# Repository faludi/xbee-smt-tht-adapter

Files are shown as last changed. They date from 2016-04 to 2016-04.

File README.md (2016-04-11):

# xbee-smt-tht-adapter
XBee SMT -> THT Adapter, including XBee PRO SX

These SMT to THT adapter boards are now updated to support the <a href="http://www.digi.com/resources/documentation/Digidocs/90001477/Default.htm">XBee PRO SX 1-watt modules</a>. This adapter will work with any surface mount XBee. The SMT module is soldered onto the top of the adapter board, and 2mm XBee THT footprint male headers are soldered to the bottom. For the XBee PRO SX, a heat sink pad connects to the ground plane layer on the PCB and helps cool the module.

This adapter uses two sets of 10 pin, 2mm SMD connection headers. These <a href="http://www.digikey.com/product-search/en?keywords=SAM1172-11-nd">11-pin break-away headers</a> work well, just be sure to break off the extra left-facing pin.

Printed circuit boards can be ordered from <a href="https://oshpark.com/shared_projects/a5fHOewn">OSH Park</a>.

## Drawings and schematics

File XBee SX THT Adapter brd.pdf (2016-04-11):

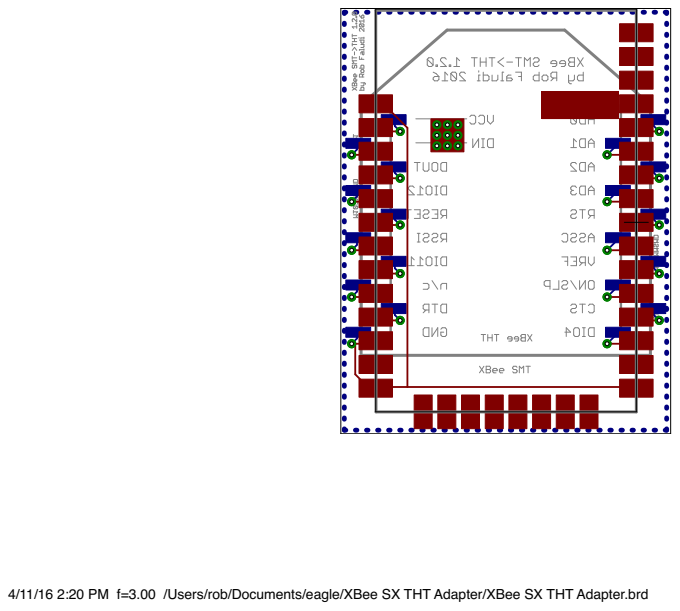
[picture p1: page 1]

4/11/16 2:20 PM f=3.00 /Users/rob/Documents/eagle/XBee SX THT Adapter/XBee SX THT Adapter.brd

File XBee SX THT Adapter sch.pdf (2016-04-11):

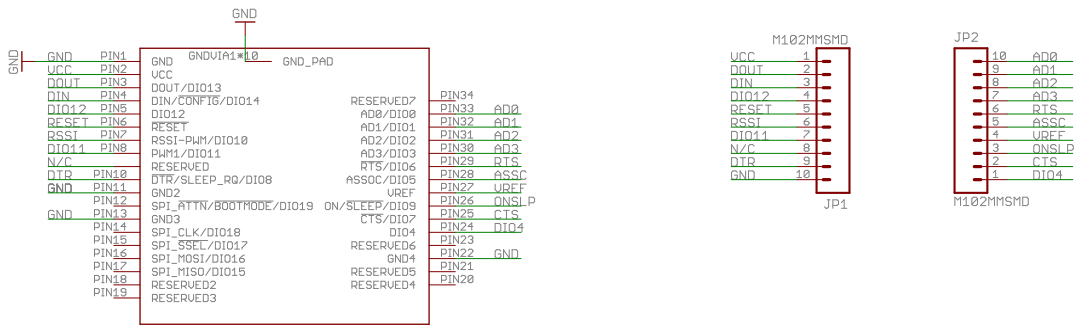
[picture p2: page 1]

4/11/16 2:20 PM f=0.99 /Users/rob/Documents/eagle/XBee SX THT Adapter/XBee SX THT Adapter.sch (Sheet: 1/1)

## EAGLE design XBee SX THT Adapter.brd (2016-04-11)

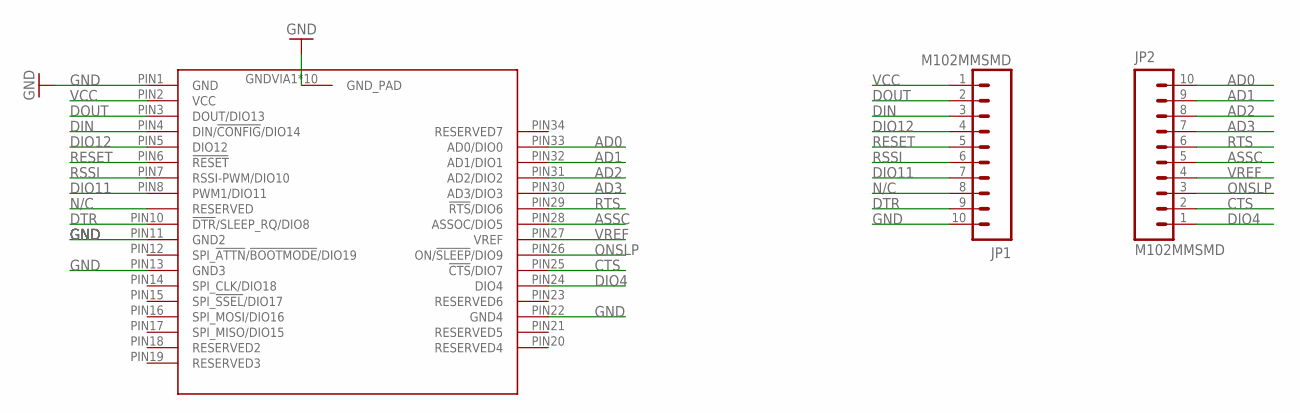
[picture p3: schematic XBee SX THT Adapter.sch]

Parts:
JP1, JP2: M102MMSMD; 1X10-2MM-SMD
U$2: XBEE-SMT; QUBIQ_FLAT-RF-SX

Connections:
AD0: JP2.10, U$2.PIN33 (AD0/DIO0)
AD1: JP2.9, U$2.PIN32 (AD1/DIO1)
AD2: JP2.8, U$2.PIN31 (AD2/DIO2)
AD3: JP2.7, U$2.PIN30 (AD3/DIO3)
ASSC: JP2.5, U$2.PIN28 (ASSOC/DIO5)
CTS: JP2.2, U$2.PIN25 (!CTS!/DIO7)
DIN: JP1.3, U$2.PIN4 (DIN/!CONFIG!/DIO14)
DIO4: JP2.1, U$2.PIN24 (DIO4)
DIO11: JP1.7, U$2.PIN8 (PWM1/DIO11)
DIO12: JP1.4, U$2.PIN5 (DIO12)
DOUT: JP1.2, U$2.PIN3 (DOUT/DIO13)
DTR: JP1.9, U$2.PIN10 (!DTR!/SLEEP_RQ/DIO8)
GND: JP1.10, U$2.GNDVIA1 (GND_PAD), U$2.GNDVIA2 (GND_PAD), U$2.GNDVIA3 (GND_PAD), U$2.GNDVIA4 (GND_PAD), U$2.GNDVIA5 (GND_PAD), U$2.GNDVIA6 (GND_PAD), U$2.GNDVIA7 (GND_PAD), U$2.GNDVIA8 (GND_PAD), U$2.GNDVIA9 (GND_PAD), U$2.GND_PAD, U$2.PIN1 (GND), U$2.PIN11 (GND2), U$2.PIN13 (GND3), U$2.PIN22 (GND4)
N/C: JP1.8, U$2.PIN9 (RESERVED)
ONSLP: JP2.3, U$2.PIN26 (ON/!SLEEP!/DIO9)
RESET: JP1.5, U$2.PIN6 (!RESET)
RSSI: JP1.6, U$2.PIN7 (RSSI-PWM/DIO10)
RTS: JP2.6, U$2.PIN29 (!RTS!/DIO6)
VCC: JP1.1, U$2.PIN2 (VCC)
VREF: JP2.4, U$2.PIN27 (VREF)

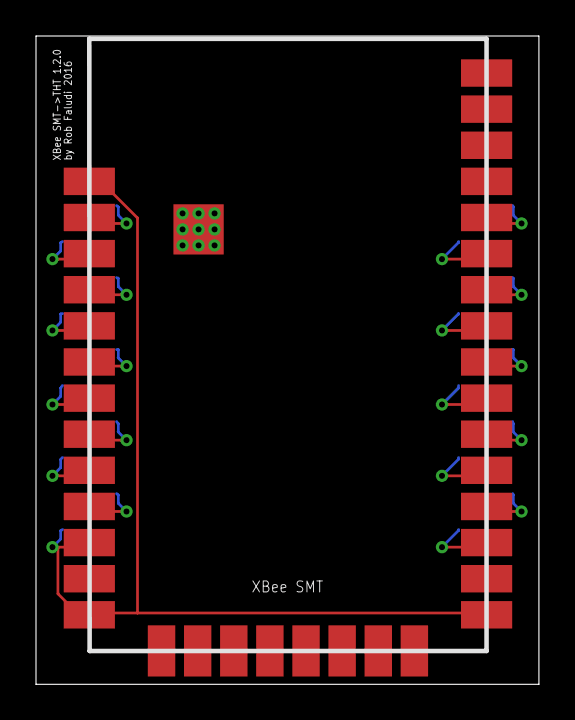
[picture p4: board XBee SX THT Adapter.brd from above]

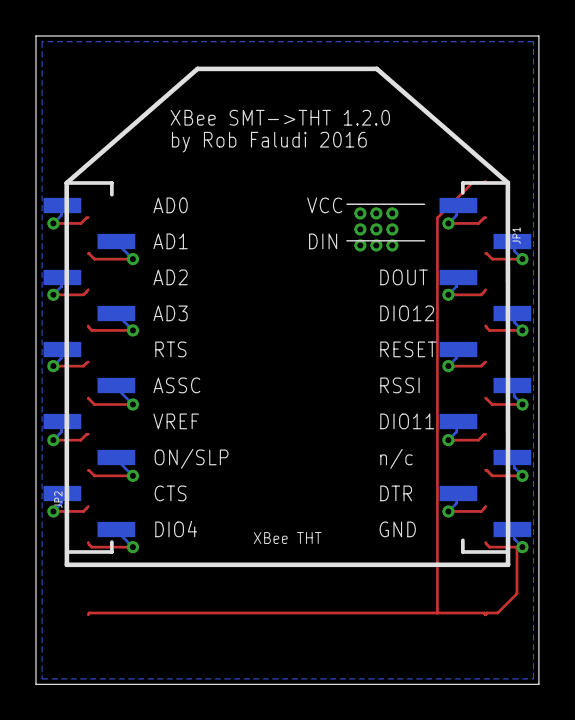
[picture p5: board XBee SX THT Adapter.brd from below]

Board: 2 copper layers, 27.9 x 36.0 mm, 3 parts (2 on the bottom side), 20 nets.

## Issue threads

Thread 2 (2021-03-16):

Add Support for Through Hole Headers

nealei, 2021-03-16:
Is it possible to add support for through-hole headers like:

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

faludi, 2021-03-16:
Yes, even without the board, though for certain modules the heat sink on the PCB is highly recommended.

nealei, 2021-03-16:
You mean yes, if I want it then do it myself? I only want the board for the heat sink.

faludi, 2021-03-16:
Yeah, this is a project from five years ago. FWIW, I also used that radio without the heat sink and it functioned fine for me. I would never put it into a manufactured product that way, but for simple prototyping it wasn't an immediate issue.

nealei, 2021-03-16:
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

https://github.com/nebkat/xbee-smd-tht-adapter-board-reference-design

Closed 2021-03-16.

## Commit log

2016-04-11 Eagle CAD board design file
    [XBee SX THT Adapter.brd]
2016-04-11 Eagle CAD schematic file
    [XBee SX THT Adapter.sch]
2016-04-11 Board layout in PDF format
2016-04-11 Schematic in PDF format
2016-05-01 Board layout in PDF format
    fixed filename
2016-05-01 Schematic in PDF format
    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

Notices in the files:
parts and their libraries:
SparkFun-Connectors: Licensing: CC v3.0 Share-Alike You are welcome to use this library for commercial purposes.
